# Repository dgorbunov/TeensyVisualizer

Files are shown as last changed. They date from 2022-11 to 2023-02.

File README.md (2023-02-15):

# TeensyVisualizer
### 14 Channel LED Matrix Music Visualizer for Teensy 4.0
*Hardware audio visualizer with line-in, built-in microphone, and configurable display modes.*

TeensyVisualizer in Rainbow Mode (https://www.youtube.com/shorts/IFxiID-yiMM)

*Click for short video*

An entirely on-chip hardware spectrum analyzer that displays frequency bins from either line-in or microphone input on an RGB LED Matrix display. Designed to work with HUB75 RGB LED Matrices, and scalable to any size. 14 bands across 40Hz - 16kHz are displayed in a variety of user changeable modes. Modes can be changed with the built-in button on the back of TeensyVisualizer and brightness can be adjusted with the onboard potentiometer. There are several display modes and color profiles to chose from, these settings are all non-volatile and stored into the Teensy's onboard EEPROM memory.

This PCB uses all hardware frequency analysis instead of software-based FFT like most Teensy-based audio visualizers. The two MSI MSGEQ7 Graphic Equalizer Display Filters compute frequency bins and decay at a logarathmic rate per sample, creating a much more realistic representation of audio than FFT. The onboard switch allows use of the built-in microphone or passthrough 3.5mm line input, both inputs feature adjustable gain through a dual op amp. A trick is used to offset the center frequencies of the 2 MSGEQ7 ICs by passing in two external clocks via the onboard SI5351A Clock Generator - this allows 14 independent frequencies to be sampled.

## Main components:
- Teensy 4.0 ARM MCU
- SmartMartix SmartLED Shield
- HUB75 64x32 P5 LED Matrix (scalable to any matrix size/pitch)
- 2x MSI MSGEQ7 Graphic Equalizer ICs
- Adafruit SI5351A Clock Generator
- LM358 Dual Channel Op Amp

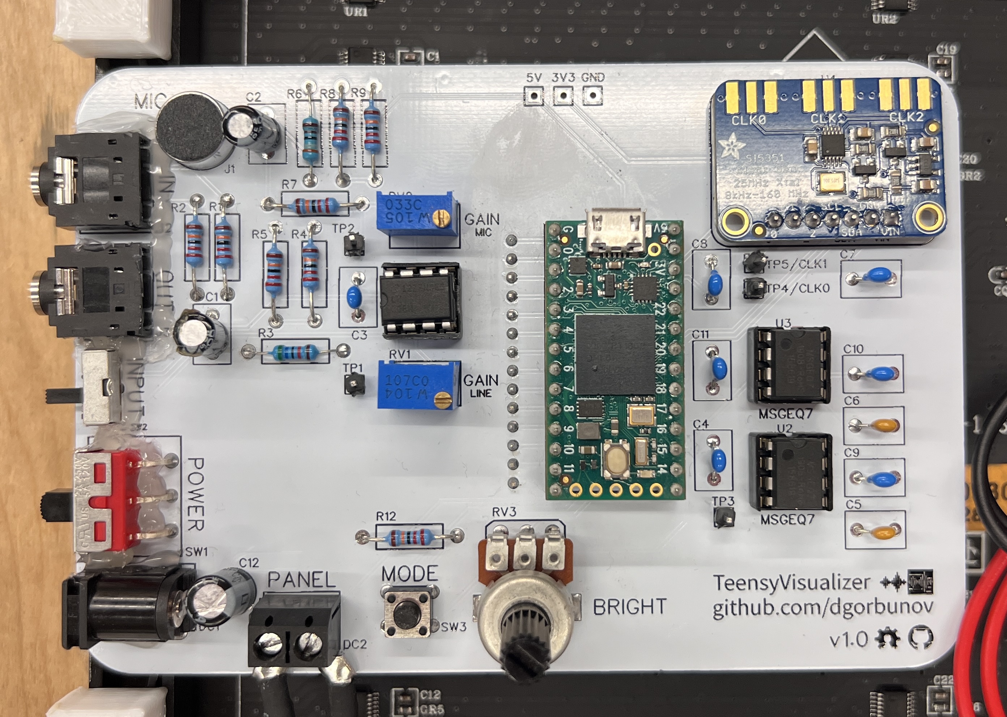
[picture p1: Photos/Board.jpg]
PCB


## Features:
- 14 Channel IC-Based Hardware Spectrum Analyzer
- Automatic scaling to any matrix size, supports daisy chaining
- Switch between 3.5mm line-in passthrough or built-in microphone
- Dual channel amplifier with adjustable gain
- Built-in 5V DC jack with on/off switch
- Onboard button to switch display modes
- Onboard knob to control display brightness
- Non-volatile setting storage
- Automatic dimming when no audio detected

## PCB/Kits
PCBs can be purchased on Tindie [here](https://www.tindie.com/products/27737/). Components can all be sourced on popular suppliers like Digi-Key or Mouser by following the Bill of Materials (BOM). Gerber files are also included if you want to fabricate the PCB yourself.

Full Kits include everything you need to build your own TeensyVisualizer, they are available for purchase through Tindie [here](https://www.tindie.com/products/27748/).

## Build It Yourself
The Bill of Materials can be found here: [BOM](https://github.com/dgorbunov/TeensyVisualizer/tree/main/BOM).
The Schematic can be found here: [Schematic](https://github.com/dgorbunov/TeensyVisualizer/blob/main/Schematic/Schematic%20V1.1.svg).
Schematic Image

## Build Instructions
1. Solder all components to the PCB per the BOM. Make sure female headers are used for any ICs including the Teensy. Solder 2x14 male header pins on the reverse side of the PCB next to the Teensy, these will be inserted in to the display driver.
2. Cut the trace between VIN and VUSB on the back of the Teensy. This prevents back-powering your computer when connected to the Teensy over USB.
3. Insert PCB with male header pins into the SmartLED Display Shield, making sure it is fully seated. Insert the 2 PCBs with Teensy on top into the male port on the LED Matrix. The TeensyVisualizer board should be flush with the edge of the matrix and sitting on top of it.
4. Attach power cable to matrix and positive and negative to the terminal block on the TeensyVisualizer PCB, clamping them down.

## Use Instructions
1. Insert 5V DC Power Barrel into connector, use large switch to turn on power.
2. Smaller switch can be used to switch between line and mic input.
3. Run TeensyVisualizer through typical sound environment levels and adjust the two onboard trimmer potentiometers to desired gain. Each takes 25 turns to reach full gain. Mic circuit has default max 100x gain and line input has default max 2x gain. Mic and line gain ratio can be adjusted past these values by changing R7 and R3 respectively.
4. Use big potentiometer to change brightness. TeensyVisualizer will automatically dim the display if no audio input is detected.
5. Press the button to cycle color profiles, hold the button to cycle through display modes.

## 3D Printed Case
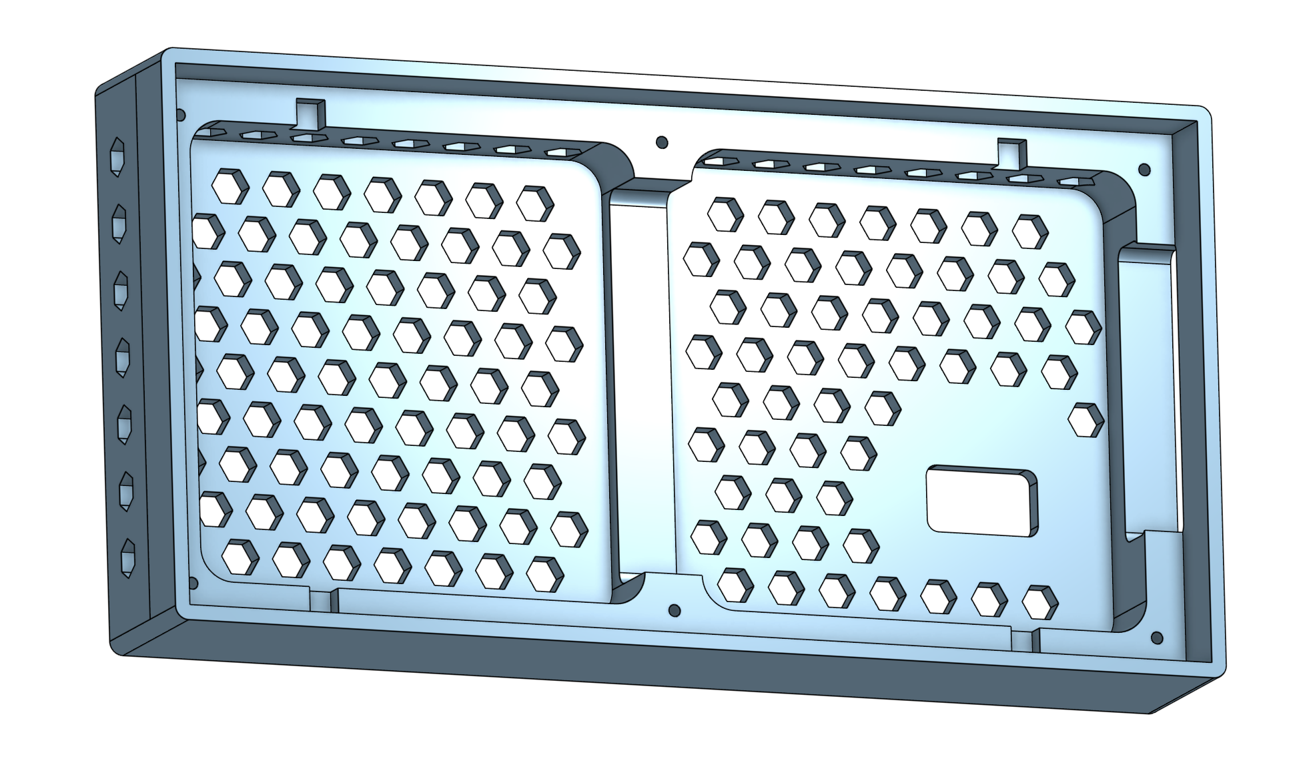
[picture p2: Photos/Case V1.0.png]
TeensyVisaulizer Case

The 3D Printed Case is included with the Kit, or you can print it yourself. This case is designed for the standard 320mm x 160mm 64x32 P5 LED Matrix and requires six M3x30mm screws.
[STL Download](https://github.com/dgorbunov/TeensyVisualizer/raw/main/Case/TeensyVisualizer%20Case%20V1.0.stl).

## Credits
Originally inspired by Mark Donner's 14 Channel Analyzer based off the ATMega2560 using FastLED. Circuit redesigned from the ground up around Teensy and 3.3V using SmartMatrix HUB75 panels and programmed from scratch.

The following open-source libraries are used:
- SmartMatrix
- SmartMatrix GFX
- FastLED
- MegunoLink
- SI5351MCU

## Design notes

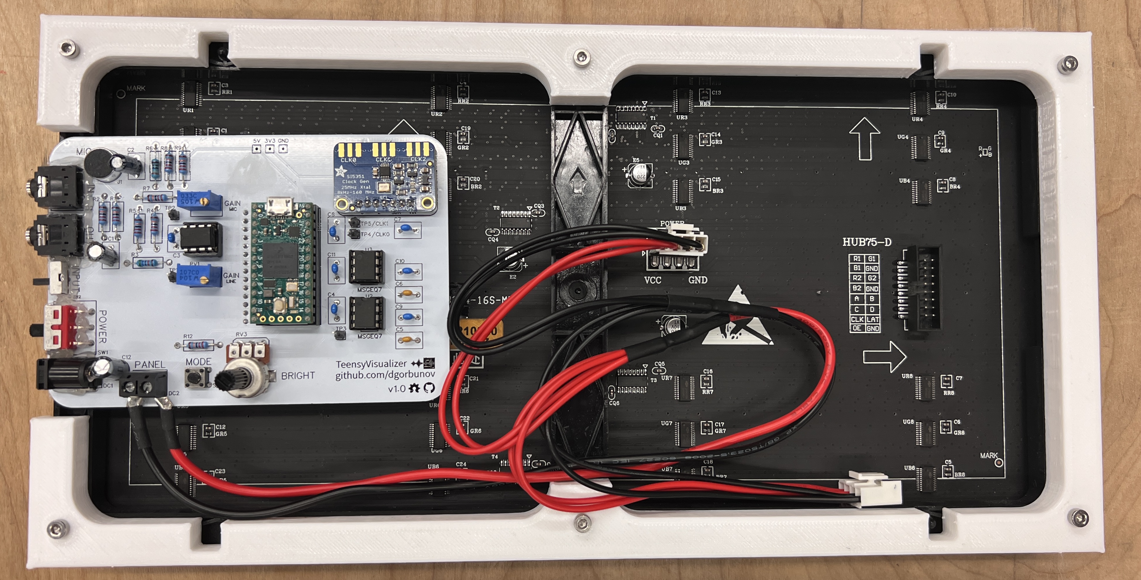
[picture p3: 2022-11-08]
Photos/Backside.jpg

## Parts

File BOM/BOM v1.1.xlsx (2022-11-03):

Teensy Visualizer v1.0 BOM |  |  | github.com/dgorbunov
ID | State | Part | Qty. | Designator | Manufacturer | Manufacturer Part | Supplier
1 | FALSE | Teensy4.0 | 1 | - | PJRC | TEENSY40 | Amazon/PJRC
2 | FALSE | SmartLED Shield V5 | 1 | - | Adafruit Industries LLC | 4828 | Mouser/Digi-Key
3 | FALSE | P5 64x32 HUB75 Panel | 1 | - | IDEALMORE | ‎P5-2121-32 | Amazon
4 | FALSE | 5V 4A PSU | 1 | - | Facmogu | A18190-MG-US | Amazon
5 | FALSE | 1uF | 2 | C1,C2 | KEMET | C333C105K5R5TA | Mouser/Digi-Key
6 | FALSE | 0.1uF | 7 | C3,C4,C7,C8,C9,C10,C11 | Vishay | K104K15X7RF5TL2 | Mouser/Digi-Key
7 | FALSE | 0.01uF | 2 | C5,C6 | Vishay | K103K15X7RF5TL2 | Mouser/Digi-Key
8 | FALSE | 470uF Radial 6.3V | 1 | C12 | Rubycon | 6.3ZLH470MEFC6.3X11 | Mouser/Digi-Key
9 | FALSE | DC Jack | 1 | DC1 | GCT | DCJ200-10-A-K1-K | Mouser/Digi-Key
10 | FALSE | Terminal Block 5mm | 1 | DC2 | Würth Elektronik | ‎691502710002 | Mouser/Digi-Key
11 | FALSE | Mic Cond. Electret | 1 | J1 | CUI Devices | CMA-4544PF-W | Mouser/Digi-Key
12 | FALSE | 3.5mm Jack Stereo | 2 | J2 | CUI Devices | SJ1-3523N | Mouser/Digi-Key
13 | FALSE | 3.9K | 1 | R6 | Stackpole Electronics Inc | CF14JT3K90 | Mouser/Digi-Key
14 | FALSE | 4.7K | 2 | R10,R11 | Stackpole Electronics Inc | CF14JT4K70 | Mouser/Digi-Key
15 | FALSE | 10K | 8 | R1,R2,R4,R5,R7,R8,R9,R12 | Stackpole Electronics Inc | CF14JT10K0 | Mouser/Digi-Key
16 | FALSE | 56K | 1 | R3 | Stackpole Electronics Inc | CF14JT100K | Mouser/Digi-Key
17 | FALSE | 100K Trimmer | 1 | RV1 | Bourns Inc. | 3296W-1-104LF | Mouser/Digi-Key
18 | FALSE | 1M Trimmer 0.5W | 1 | RV2 | Bourns Inc. | PV36W105C01B00 | Mouser/Digi-Key
19 | FALSE | 10K Pot 0.05W | 1 | RV3 | TT Electronics/BI | P120PK-Y25BR10K | Mouser/Digi-Key
20 | FALSE | Switch 5A SPDT | 1 | SW1 | E-Switch | 500SSP1S1M6QEA | Mouser/Digi-Key
21 | FALSE | Switch 200mA SPDT | 1 | SW2 | E-Switch | EG1213 | Mouser/Digi-Key
22 | FALSE | Pushbutton 6x6mm | 1 | SW3 | Omron Electronics Inc | B3F-1020 | Mouser/Digi-Key
23 | FALSE | LM358N 8DIP | 1 | U1 | Texas Instruments | LM358P | Mouser/Digi-Key
24 | FALSE | MSGEQ7 8DIP | 2 | U2, U3 | SparkFun | COM-10468 | Mouser
25 | FALSE | Si5351A Board | 1 | U4 | Adafruit Industries LLC | 2045 | Mouser/Digi-Key
26 | FALSE | Teensy Header | 1 | - | Adafruit Industries LLC | 4174 | Mouser/Digi-Key
27 | FALSE | SI5351A Header | 1 | - | Sullins Connector Solutions | PPPC071LFBN-RC | Mouser/Digi-Key
28 | FALSE | 8DIP Socket | 3 | - | Assmann WSW Components | A 08-LC-TT | Mouser/Digi-Key
29 | FALSE | Knob Ribbed | 1 | - | Adafruit Industries LLC | 2047 | Mouser/Digi-Key

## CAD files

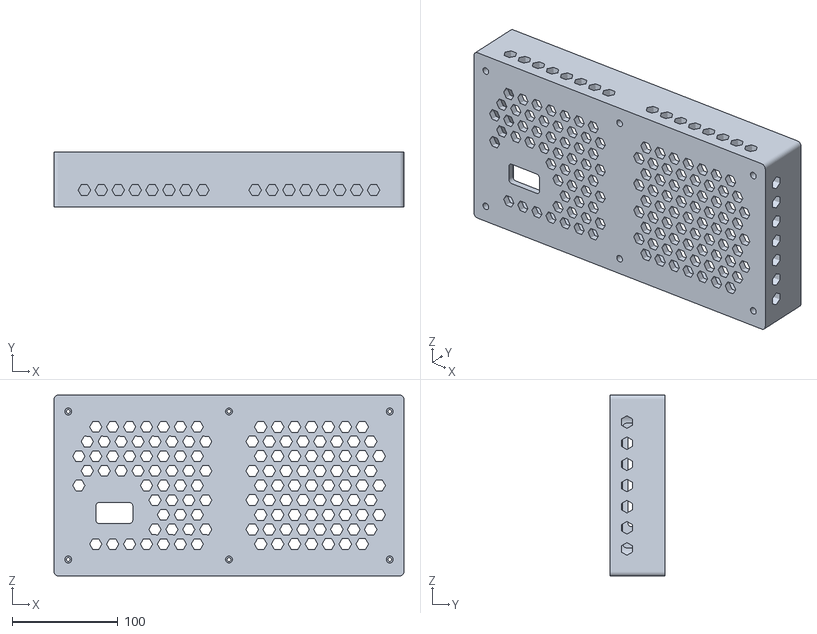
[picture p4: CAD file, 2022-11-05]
Case/TeensyVisualizer Case V1.0.stl
331.0 x 52.0 x 171.0

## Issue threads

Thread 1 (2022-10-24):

PCB v2.0 Feature List

dgorbunov, 2022-10-24:
- Separate, low profile, extension board connected to SmartLED Shield via ribbon cable
- Extension board sits atop backside lip of LED Matrix, spans entire height of one matrix
- Adhesive/glue to LED Matrix, holes to interface with threads on edge of LED Matrix
- Potential separate header board for cable attached to SmartLED Shield

- All I/O, buttons, pots interface moved to side of the board
- 3D Printed enclosure with holes for matrix extensions and I/O shield
- Use all SMD Components:
- SOIC-8 package for ICs (MSGEQ7, Amps)
- SMD resistors/capacitors
- MAX9814 Chip for Mic Amp w/ AGC
- AGC chip for line input
- Dual RCA + 3.5mm input/output
- Cheaper component sourcing; black pcb

dgorbunov, 2022-10-24:
Known issues with v1.0 design:

- Mic amplifier may not work
- Voltage test headers can interfere with the USB port.
- Poor mechanical stability without adhering the board

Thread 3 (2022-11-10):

Static Color Causes Noise

dgorbunov, 2022-11-10:
Display, when showing any static color (this was noticed primarily when showing white), increases frequency noise significantly and adds garbage to output signal. Could be related to current draw or datalines to matrix shield.

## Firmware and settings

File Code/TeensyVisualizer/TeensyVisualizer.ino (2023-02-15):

/* 
 *  TeensyVisualizer, 14 Channel Audio Visualizer for Teensy 4.0 using HUB75 LED Matrices.
 *  Author: Daniel Gorbunov. Instructions, PCB, Schematics, and Code available on GitHub.
 *  Code v2.01, November 2022. MIT License. github.com/dgorbunov/TeensyVisualizer
 *  
 *  The following libraries must be installed to use this software: 
 *  SmartMatrix, SmartMatrix GFX, FastLED, MegunoLink, SI5351MCU
 */

#include <MatrixHardware_Teensy4_ShieldV5.h>  // Choose based on your Teensy and shield version
#include <EEPROM.h>
#include <SmartMatrix.h>
#include <FastLED.h>
#include <si5351mcu.h>
#include <MegunoLink.h>
#include <Filter.h>
#include <map>

#define COLOR_DEPTH 24                  // Choose the color depth used for storing pixels in the layers: 24 or 48 (24 is good for most sketches)
const uint16_t kMatrixWidth = 64;       // Set to the width of your display, must be a multiple of 8
const uint16_t kMatrixHeight = 32;      // Set to the height of your display
const uint8_t kRefreshDepth = 48;       // Tradeoff of color quality vs refresh rate, max brightness, and RAM usage.  36 is typically good, drop down to 24 if you need to.  On Teensy, multiples of 3, up to 48: 3, 6, 9, 12, 15, 18, 21, 24, 27, 30, 33, 36, 39, 42, 45, 48.
const uint8_t kDmaBufferRows = 4;       // known working: 2-4, use 2 to save RAM, more to keep from dropping frames and automatically lowering refresh rate.  (This isn't used on ESP32, leave as default)
const uint8_t kPanelType = SM_PANELTYPE_HUB75_32ROW_MOD16SCAN;  // Choose the configuration that matches your panels.  See more details in MatrixCommonHub75.h and the docs: https://github.com/pixelmatix/SmartMatrix/wiki
const uint32_t kMatrixOptions = (SM_HUB75_OPTIONS_NONE);        // see docs for options: https://github.com/pixelmatix/SmartMatrix/wiki
const uint8_t kBackgroundLayerOptions = (SM_BACKGROUND_OPTIONS_NONE);

SMARTMATRIX_ALLOCATE_BUFFERS(matrix, kMatrixWidth, kMatrixHeight, kRefreshDepth, kDmaBufferRows, kPanelType, kMatrixOptions);
SMARTMATRIX_ALLOCATE_BACKGROUND_LAYER(backgroundLayer, kMatrixWidth, kMatrixHeight, COLOR_DEPTH, kBackgroundLayerOptions);

#define NOISE 100             // 0-1023, noise subtracted from signaal
#define NOISE_TOLERANCE 1.2  // NOISE_TOLERANCE * NOISE = minimum noise to go into idle
#define NOISE_THRESHOLD 2    // Multiplied by noise for minimum value to display bin
#define SMOOTHING 72         // 100 = no smoothing, 0 = full smoothing
#define TARGET_FPS 28        // 0-60, frames per second. Higher FPS = faster decay due to more sampling
#define ADDRESS_MODE 0       // Memory address for currentMode, default 0
#define ADDRESS_COLOR 1      // Memory address for color, default 1

// Required values for TeensyVisualizer PCB
#define BRIGHTNESS_PIN 16  // Brightness potentiometer
#define MODE_PIN 17        // currentMode pushbutton
#define STROBE_PIN 22      // MSGEQ7 combined strobe
#define RESET_PIN 23       // MSGEQ7 combined reset
#define OUT_PIN_0 14       // MSGEQ7_0 output (this is A0/14 on Teensy 4.0)
#define OUT_PIN_1 15       // MSGEQ7_1 output (this is A1/15 on Teensy 4.0)

// SI5351A Frequencies - default for 14 channel sweep
uint32_t CLK_FREQ_0 = 104570; // MSGEQ7 clock freq. 0
uint32_t CLK_FREQ_1 = 166280; // MSGEQ7 clock freq. 1 

int binWidth = 14;                // Calculates width based on display size
int binPadding = 4;               // Calculates padding to center graphics
unsigned long timeQuiet = 0;
bool isQuiet = false;
int correctedFPS = TARGET_FPS;
float currentBrightness = 0;
float startBrightness = 0;

bool buttonPressed = false;           // Stores whether button has been pressed
bool modeChanged = false;             // Stores whether mode has been changed
unsigned long timeButtonPressed = 0;  // Initial time that the button was pressed
unsigned long modeSwitchTime = 650;   // Time required holding button to change currentMode

unsigned long waveCycleTime = 4000; // Gradient wave cycle time
unsigned long waveStartTime = 0;    // Gradient wave start timer

// TODO: Bezier curves
std::map<int, String> modes = 
{
  {0, "Lines"}, 
  {1, "Blocks"},
  {2, "Levels"},
  {3, "Bounce"},
};

// TODO: Rainbow hue based on peak height
std::map<int, String> colors = 
{
  {0, "Rainbow"},
  {1, "Wave"},
  {2, "Heat"}
};

unsigned int currentMode = 0;
unsigned int currentColor = 0;

Si5351mcu si;
ExponentialFilter<int> * BinFilters[14];

void setup() {
//  Serial.begin(115200);

  // Initialize matrix
  matrix.addLayer(&backgroundLayer); 
  matrix.begin();
  backgroundLayer.enableColorCorrection(true);

  // Draw startup graphics
  backgroundLayer.fillScreen({0,0,0});
  backgroundLayer.swapBuffers();
  backgroundLayer.setFont(font6x10);
  backgroundLayer.drawString(14, 1, {255,0,0}, "Teensy");
  backgroundLayer.drawString(2, 11, {255,0,0}, "Visualizer");
  backgroundLayer.setFont(font3x5);
  backgroundLayer.drawString(14, 24, {255,255,255}, "14 Channel");
  backgroundLayer.swapBuffers();

  // Set binWidth and padding based on matrix size
  binWidth = (kMatrixWidth / 14);
  binPadding = (kMatrixWidth - (binWidth * 14)) / 2;

  // Create 14 ExponentialFilters for frequency bins
  for (int i = 0; i < 14; i++) {
    BinFilters[i] =  new ExponentialFilter<int>(SMOOTHING, 0);
  }

  // Write to EEPROM if blank, otherwise read mode and color data
  if (EEPROM.read(ADDRESS_MODE) == 0xFF) {
    EEPROM.write(ADDRESS_MODE, currentMode);
  } else {
    currentMode = EEPROM.read(ADDRESS_MODE);
  }
  
  if (EEPROM.read(ADDRESS_COLOR) == 0xFF) {
    EEPROM.write(ADDRESS_COLOR, currentColor);
  } else {
    currentColor = EEPROM.read(ADDRESS_COLOR);
  }

  // Setup pins
  pinMode(MODE_PIN, INPUT);
  pinMode(BRIGHTNESS_PIN, INPUT);
  pinMode(STROBE_PIN, OUTPUT);
  pinMode(RESET_PIN, OUTPUT);
  pinMode(OUT_PIN_0, INPUT);
  pinMode(OUT_PIN_1, INPUT);

  // MSGEQ7 initial state
  digitalWrite(RESET_PIN,  LOW);
  digitalWrite(STROBE_PIN, LOW);

  // Setup SI5351
  si.init(25000000L);
  si.setFreq(0, CLK_FREQ_0);
  si.setFreq(1, CLK_FREQ_1);
  si.setPower(0, SIOUT_8mA);
  si.setPower(1, SIOUT_8mA);
  si.enable(0);
  si.enable(1);

  // float Animation
  const float mult = (220 / (kMatrixWidth - 1));
  for (int i = 0; i < kMatrixWidth; i++) {
    backgroundLayer.setFont(font6x10);
    backgroundLayer.drawString(14, 1, CRGB(CHSV(mult * i, 255, 255)), "Teensy");
    backgroundLayer.drawString(2, 11, CRGB(CHSV(mult * i, 255, 255)), "Visualizer");
    backgroundLayer.setFont(font3x5);
    backgroundLayer.drawString(14, 24, {255,255,255}, "14 Channel");
    backgroundLayer.fillRectangle(i, kMatrixHeight - 1, i, kMatrixHeight - 2, CRGB(CHSV(mult * i, 255, 255)));
    backgroundLayer.swapBuffers();
    delay(35);
  }
  
  backgroundLayer.fillScreen({0,0,0});
  backgroundLayer.swapBuffers(false);
}

void loop() {
  unsigned long loopStartTime = millis();
  
  readFrequencies();
  autoDim();

  // If FPS below target, draw white pixel in upper right
  if (correctedFPS < TARGET_FPS - 2) {
    backgroundLayer.drawPixel(kMatrixWidth - 1, 0, {255,255,255});
//    Serial.println("Low FPS");
  }
  
  int buttonState = digitalRead(MODE_PIN);
  if (buttonState && !buttonPressed) {
    buttonPressed = true;
    modeChanged = false;
    timeButtonPressed = millis();
  } 
  // button depress
  else if (!buttonState && buttonPressed && loopStartTime - timeButtonPressed <= modeSwitchTime) {
    buttonPressed = false;

    // color change case
    if (!modeChanged) {
      currentColor = (currentColor == colors.size() - 1) ? 0 : currentColor + 1;
      EEPROM.write(ADDRESS_COLOR, currentColor);
    } else {
      // if mode was changed, don't also change color on button depress
      modeChanged = false;
    }
  } 

  // mode change case
  else if (buttonPressed && loopStartTime - timeButtonPressed > modeSwitchTime) {
    timeButtonPressed = millis();
    modeChanged = true;
    
    currentMode = (currentMode == modes.size() - 1) ? 0 : currentMode + 1;
    EEPROM.write(ADDRESS_MODE, currentMode);
  }

  String color = colors.at(currentColor);
//  Serial.println("Mode: " + modes.at(currentMode));
//  Serial.println("Color: " + color);

  switch(currentMode) {
    case 0:
      lines(false, color);
      break;
    case 1:
      blocks(true, color);
      break;
    case 2:
      blocks(false, color);
      break;
    case 3:
      bounce(false, color);
      break;
    default:
      lines(false, color);
      break;
  }
  
  // Swap layer to render buffer
  backgroundLayer.swapBuffers(false);

  // Add delay to correct FPS to target
  int uncorrectedFPS = 1.0 / ((millis() - loopStartTime) / 1000.0);
  if (uncorrectedFPS > TARGET_FPS) {
    delay((1.0 / TARGET_FPS - 1.0 / uncorrectedFPS) * 1000.0);
  }
  
  correctedFPS = 1.0 / ((millis() - loopStartTime) / 1000.0);
//  Serial.println("FPS: " + (String) correctedFPS);
}

// Lines drawn between the peaks of each channel
void lines(boolean filled, String color){
  SM_RGB currentColor = CRGB(0,0,0);
  
  for (int i = 0, x = binPadding / 2; i < 15; i++, x += binWidth) {
    int peak = getPeakValue(i-1);
    int nextPeak = getPeakValue(i);
    
    if (color == "Heat") {
      if (i == 0) currentColor = CRGB(CHSV(100 - nextPeak * 3.2, 255, 255));
      else currentColor = CRGB(CHSV(100 - peak * 3.2, 255, 255));
    } else if (color == "Wave") {
      currentColor = CRGB(CHSV((i) * 16 + getWaveModifier(), 255, 255));
    } else {
      currentColor = CRGB(CHSV((i) * 16, 255, 255));
    }

    backgroundLayer.drawLine(x, (kMatrixHeight - 1) - peak, x + (binWidth - 1), (kMatrixHeight - 1) - nextPeak, currentColor);
  }
}

// Version of lines that expands outward in mirror effect from center
void bounce(boolean filled, String color) {
  SM_RGB currentColor = CRGB(0,0,0);

  for (int i = 0, x = binPadding / 2; i < 15; i++, x += binWidth) {
    int peak = getPeakValue(i-1);
    int nextPeak = getPeakValue(i);
    
    if (color == "Heat") {
      if (i == 0) currentColor = CRGB(CHSV(100 - nextPeak * 3.2, 255, 255));
      else currentColor = CRGB(CHSV(100 - peak * 3.2, 255, 255));
    } else if (color == "Wave") {
      currentColor = CRGB(CHSV((i) * 16 + getWaveModifier(), 255, 255));
//      SM_RGB currentColorPhased = CRGB(CHSV((i) * 16 + getWaveModifier() + 127, 255, 255));
    } else {
      currentColor = CRGB(CHSV((i) * 16, 255, 255));
    }

    backgroundLayer.drawLine(x, (kMatrixHeight / 2) - 1 - (peak / 2), x + (binWidth - 1), (kMatrixHeight / 2) - 1 - (nextPeak / 2), currentColor); // draw upwards facing lines
    backgroundLayer.drawLine(x, (kMatrixHeight / 2) + (peak / 2), x + (binWidth - 1), (kMatrixHeight / 2) + (nextPeak / 2), currentColor); // draw downwards facing lines
  }
}

// Blocks of binWidth drawn up to the peaks of each channel
// TODO: Peak detection/falling peaks
void blocks(boolean filled, String color) {
  SM_RGB currentColor = CRGB(0,0,0);
  
  for (int i = 0, x = binPadding; i < 14; i++, x += binWidth) {
    int peak = getPeakValue(i);
    
    if (color == "Heat") {
      currentColor = CRGB(CHSV(100 - peak * 3.2, 255, 255));
    } else if (color == "Wave") {
      currentColor = CRGB(CHSV((i) * 17 + getWaveModifier(), 255, 255));
    } else {
      currentColor = CRGB(CHSV((i) * 17, 255, 255));
    }    
    
    if (filled) backgroundLayer.fillRectangle(x, kMatrixHeight - 1, x + binWidth - 1, kMatrixHeight - 1 - peak, currentColor);
    else backgroundLayer.drawLine(x, kMatrixHeight - 1 - peak, x + binWidth - 1, kMatrixHeight - 1 - peak, currentColor);
  }
}

// algorithm from http://www.netgraphics.sk/bresenham-algorithm-for-a-line
void drawLine(int16_t x1, int16_t y1, int16_t x2, int16_t y2, const rgb24 color) {
    // if point x1, y1 is on the right side of point x2, y2, change them
    if ((x1 - x2) > 0) {
        drawLine(x2, y2, x1, y1, color);
        return;
    }
    // test inclination of line
    // function Math.abs(y) defines absolute value y
    if (abs(y2 - y1) > abs(x2 - x1)) {
        // line and y axis angle is less then 45 degrees
        // thats why go on the next procedure
        bresteepline(y1, x1, y2, x2, color); return;
    }
    // line and x axis angle is less then 45 degrees, so x is guiding
    // auxiliary variables
    int x = x1, y = y1, sum = x2 - x1, Dx = 2 * (x2 - x1), Dy = abs(2 * (y2 - y1));
    int prirastokDy = ((y2 - y1) > 0) ? 1 : -1;
    // draw line
    for (int i = 0; i <= x2 - x1; i++) {
        backgroundLayer.drawPixel(x, y, color);
        x++;
        sum -= Dy;
        if (sum < 0) {
            y = y + prirastokDy;
            sum += Dx;
        }
    }
}

void bresteepline(int16_t x3, int16_t y3, int16_t x4, int16_t y4, const rgb24 color) {
    // if point x3, y3 is on the right side of point x4, y4, change them
    if ((x3 - x4) > 0) {
        bresteepline(x4, y4, x3, y3, color);
        return;
    }

    int x = x3, y = y3, sum = x4 - x3,  Dx = 2 * (x4 - x3), Dy = abs(2 * (y4 - y3));
    int prirastokDy = ((y4 - y3) > 0) ? 1 : -1;

    for (int i = 0; i <= x4 - x3; i++) {
        backgroundLayer.drawPixel(y, x, color);
        x++;
        sum -= Dy;
        if (sum < 0) {
            y = y + prirastokDy;
            sum += Dx;
        }
    }
}

int getPeakValue(int index) {
  if (index < 0 || index >= 14) return 0;
  return ((max((BinFilters[index]->Current() - NOISE), 0) / 1023.0) * kMatrixHeight);
}

float getWaveModifier() {
  unsigned long elapsedTime = millis() - waveStartTime;
  
  if (waveStartTime == 0 || elapsedTime >= waveCycleTime) {
    waveStartTime = millis();
    return 0;
  } else {
    return elapsedTime * (255.0 / waveCycleTime);
  }
}

// Detect the noisefloor and go dark if no sound is being played
void autoDim() {
  float avgLevel = 0;
  unsigned long fadeTime = 2000;
  unsigned long waitToFadeTime = 8000;
  
  for (int i = 0; i < 14; i++) {
    avgLevel += BinFilters[i]->Current();
  }

  avgLevel /= 14.0;

  if (!isQuiet && avgLevel < NOISE * NOISE_TOLERANCE) {
    timeQuiet = millis();
    isQuiet = true;
    
  } else if (isQuiet && avgLevel >= NOISE * NOISE_TOLERANCE) {
    isQuiet = false;
  }
  
  backgroundLayer.fillScreen({0,0,0});
  int userBrightness = ceil(analogRead(BRIGHTNESS_PIN) / 1023.0 * 255);
  
  if (isQuiet && millis() - timeQuiet > waitToFadeTime) {
    if (millis() - timeQuiet > waitToFadeTime + fadeTime) {
      currentBrightness = 0;
    } else if (currentBrightness > 0) {
      currentBrightness -= userBrightness / (fadeTime / (1000.0/correctedFPS)); // brightness / (fadeTime / (ms per frame))
    }
    
  } else {
    currentBrightness = (userBrightness < 2) ? 0 : userBrightness;
  }

  matrix.setBrightness(max(currentBrightness, 0)); //limit brightness to positives only
}

// Read and bin frequencies from MSGEQ7 chips
void readFrequencies() {
  int levelBin[2][7];
  
  // Initial state for MSGEQ7
  digitalWrite(STROBE_PIN,  HIGH);
  digitalWrite(RESET_PIN,  HIGH);
  digitalWrite(RESET_PIN, LOW);
  delayMicroseconds(75);

  // Pulse the strobe to cycle through frequency bands
  for (int i = 0; i < 7; i++) {
    digitalWrite(STROBE_PIN, LOW);
    delayMicroseconds(40);
    
    levelBin[0][i] = analogRead(OUT_PIN_0);
    levelBin[1][i] = analogRead(OUT_PIN_1);
    
    digitalWrite(STROBE_PIN, HIGH);
    delayMicroseconds(40);
  }
  
  // Assemble 14 bands of filtered amplitudes
  for (int i = 0, n = 0; i < 14; i++) {
    if (i % 2 == 0) {
      BinFilters[i]->Filter(levelBin[0][n]);
    } else {
      BinFilters[i]->Filter(levelBin[1][n++]);
    }
  }
}

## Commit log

2022-08-18 Add v1.0 files
    [BOM V1.0.xlsx]
2022-08-22 Update BOM
    [BOM V1.0.xlsx]
2022-11-03 Fix incorrect resistor values
    [BOM V1.0.xlsx, BOM v1.1.xlsx]
2022-11-03 Fix min brightness and heat map
    [TeensyVisualizer.ino]
2022-11-05 Add 3D printed case files
    [TeensyVisualizer Case V1.0.stl]
2022-11-05 Update readme with case files
2022-11-08 Add board photos
2023-02-02 Update readme for pcb ppl :)
2023-02-15 Remove serial prints
